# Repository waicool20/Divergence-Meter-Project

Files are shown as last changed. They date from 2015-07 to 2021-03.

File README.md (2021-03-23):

# Divergence Meter Project

This project is now archived, please head over to https://github.com/waicool20/Divergence-Meter-Project-v2 for latest iteration of the project

## Introduction
Hi~ I'm waicool20, this is the Divergence Meter Project! Just in case you're wondering what project this is about, it's actually a project to make the Divergence Meter from the anime Steins;Gate a reality (If you still don't know what that is, then I'm gonna start questioning why you're here lol, go google it). Basically it displays the current world line you're in. 

Well anyways originally this project is based on this guy's project: http://www.mindspring.com/~tomtitor/ and it has helped greatly so I guess give him some credit? I tried to improve his design by improving electronics design with power efficiency and mind-friendliness in mind (hence the AVR so we can code in C :D) I designed the thing in Diptrace, but I have also included Gerber/Drill files in a convenient zip so you can just hand it to some manufacturer to make some boards (remember to remind them that it's 2 separate boards in a single zip and not one!) included also are the schematic PDFs which are not quite convenient... orz anyways have a look around.

I just pulled this off my blog ( http://waicool20.com ) and it's not all the differences I think...feel free to help me expand this list :p

> Additional Features:
> - 5 switches possible! Could be less if you tweak the software
> - Buzzer/Speaker output 😀 hurray for alarms in the morning
> - Light Sensor to detect night time to conserve power and extend Nixie tube life (could probably act as a basic motion sensor with some software magic)
> - Improvements/Slight changes:
> - Should be able to fit 2x9V batteries instead of one so more portable cosplay time :D
> - Should be able to fit 2xAA RTC backup battery so it keeps track of time accurately for theoretically over a year.
> - Interrupt based instead of Polling to conserve even more battery
> - Uses the larger but cheaper and more available version of the HV5622
> - Integrated switching power supply instead of a bought module
> - Uses an AVR instead of a PIC (I chose it because it can be reprogrammed by AVR tools and a PICKIT2 if you happen to have any of those)
> - Mostly SMD parts to make look all good when your showing off the innards XD
> - Miku silhouette included
>
> Limitations:
> - Can only use the DS3232 RTC and not the DS1307

Features in a nutshell:
- 2 Alarms
- Adaptive Brightness (Brightness changes according to surroundings)
- Turn on/off display at certain times.
- 9V battery for portability and DC Jack for stationary setups
- 5 buttons for control
- Custom World Lines
- 32 Preset world lines from the anime/VN

## Project Structure
Well the Hardware and Software git branches are separate so that they can be developed independently easily.

Basically if you want the latest Software changes please switch to the software branch. Same thing for hardware. Though most often it will be the software branch that will be updated.

## About the licensing...
Well to keep it simple the hardware and the software are licensed with the TAPR OHL and GPLv3 respectively, if you are gonna use my work feel free to contact me at waicool20@gmail.com or not if that's how you swing. 

## Safety Disclaimer
**THIS PROJECT CONTAINS HIGH VOLTAGES (~170V) IT CAN KILL YOU IN THE WORST CASE SO BE CAREFUL.**  

The project has already minimized risk of contact with High Voltage (assuming you have a solder mask) so the only places you need to be careful are the parts around the LM3481, the HV pin on the board connector, and most of the pins on the Nixie Board. When constructing the device, please make sure no high voltage areas touch the case or anything that's not supposed to be "live", like seriously it will make your life easier.

When handling this device be aware that high voltage can still exist even when the device is completely powered off because of residual power in the capacitors, wait at least 3-5 seconds before touching anything on the pcb after unplugging the device.

Well you are at your own risk when you attempt this project, you can't hold me liable for anything that happens to you, your property or anybody/thing affected by your actions. 

El Psy Congroo,  
waicool20

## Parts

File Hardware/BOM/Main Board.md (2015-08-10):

| RefDes | Value | Name | Quantity |
|:---:|:---:|:---:|:---:|
| B1 | | CR2032 Bat. Holder | 1 |
| C1, C2, C3, C4, C6, C8, C10, C13 | 0.1uF | CAP_0805 | 8 |
| C5, C7, C9 |  100uF 16V | E. Cap 2 5D | 3 |
| C11 | 4.7uF 250V | E. Cap 3.5 8D | 1 |
| C12 | | F1772-410-2200-E3 | 1 |
| | | Any safety capacitor with 10 or 15mm pin pitch will do, capacitance should be 0.1uF | |
| D1 | | PMLL4148L | 1 |
| D2 | | MUR240 | 1 |
| J1 | | HDR-1x6 | 1 |
| J2 | | AVRISP | 1 |
| J3 | | DC Plug | 1 |
| J4 | | Power Select | 1 |
| J5 | | Battery | 1 |
| J6 | | ON/OFF | 1 |
| J7 | | SW1 | 1 |
| J8 | | SW2 | 1 |
| J9 | | SW3 | 1 |
| J10 | | SW4 | 1 |
| J11 | | SW5 | 1 |
| J12 | | SPEAKER | 1 |
| J13 | | LDR | 1 |
| | | The above pin headers (J1-J13) are optional, you can solder the wires directly to the PCB instead, refer to schematic for how many pins they are,
| J14 | | Board connector | 1 |
| L1 | 2.2uH | D52LC | 1 |
| L2 | 100uH | ELC16B101L | 1 |
|										  	 |			| As for the above 2 inductors I didn't actually use those parts, instead I had a factory custom make some for me. Iirc they were 1.5A and 4A rated respectively. |
| Q1 | | 2N4401 | 1 |
| Q2 | | IPB17N25S3-100  | 1 |
| | | Any mosfet with rating above 250V+ should do, but efficiency may drop if switch on/off is too slow |
| R1, R2, R3, R4, R5, R6, R7, R8, R9, R10, R11 | 1K | RES_0805 | 11 |
| R12 | 390K | RES_0805 | 1 |
| R13, R21, R22 | 100K | RES_0805 | 3 |
| R14 | 75K | RES_0805 | 1 |
| R15, R16, R17 | 200K | RES_0805 | 3 |
| R18 | 1.5K | RES_0805 | 1 |
| R19, R23, R24, R25, R26 | 4.7K | RES_0805 | 5 |
| R20 | 0.015 | RES_2512 | 1 |
| U1 | | ATtiny861A-SU | 1 |
| U2 | | DS3232SN# | 1 |
| U3 | | TPS62160DGKT | 1 |
| U4 | | LM3481MM/NOPB | 1 |

Resistor and capacitors specifications don't really matter, just keep the tolerance low and keep it in the same package (I just pulled those off the shelf, don't even know what brand they were XD )

Sorry if some of the above parts can be a little misleading as I mostly just pulled this off the BOM export function of diptrace. So please refer to the schematics or board files and check what that part actually is using the RefDes

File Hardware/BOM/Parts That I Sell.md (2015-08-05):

## Parts I sell, go shoot me an email at waicool20@gmail.com (All prices in USD):

| Part | Price | Usage |
|:----:|:-----:|:-----:|
| PCB  | $20 each, $40 for both boards | Well where else are you gonna solder all those parts together? |
| DC-DC converter inductors x2 | $3 | One of these are for the low voltage supply and the other for the high voltage supply |
| HV Safety Capacitors x 4 | $2 | 3 for ornament use and the other one for actual use on the high voltage supply circuit |
| Dummy super capacitor | $.75 | It's the left most capacitor you see on the divergence meter |
| IPB17N25S3-100 | $1 | Once again for the high voltage supply |
| DS3232SN | $7 | Real Time Clock IC for keeping time |
| Other parts | I pretty much have everything else in large amounts like misc resistors, capacitors, switches, battery holders etc. but I think it would cheaper if you just went to a local electronics store. The only things I don't have though are the ICs used in this project except for the the attiny861a. Have to think of a way to program SMD parts first though =__= |

You choose and pay for the shipping (From Hong Kong). Normal mail, speed mail, fedex, ups etc. I think we pretty much have every kind of delivery company here :/ but ehh some of them are crazy expensive.

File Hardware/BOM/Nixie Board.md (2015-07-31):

| RefDes | Value | Name | Quantity |
|---|---|---|---|
| C1, C2, C3 | 0.1uF | CAP_0805 | 3 |
| J1 | | PPTC071LFBN-RC | 1 |
| R1, R2, R3, R4, R5, R6, R7, R8 | 68K | RES400 | 8 |
| R9, R10, R11, R12, R13, R14, R15, R16, R17, R18, R19, R20, R21, R22, R23, R24 | 510K  | RES400 | 16 |
| U1, U2, U3 | | HV5622 | 3 |
| V1, V2, V3, V4, V5, V6, V7, V8 | | IN-14 - Inverted | 8 |

Sorry if some of the above parts can be a little misleading as I mostly just pulled this off the BOM export function of diptrace. So please refer to the schematics or board files and check what that part actually is using the RefDes

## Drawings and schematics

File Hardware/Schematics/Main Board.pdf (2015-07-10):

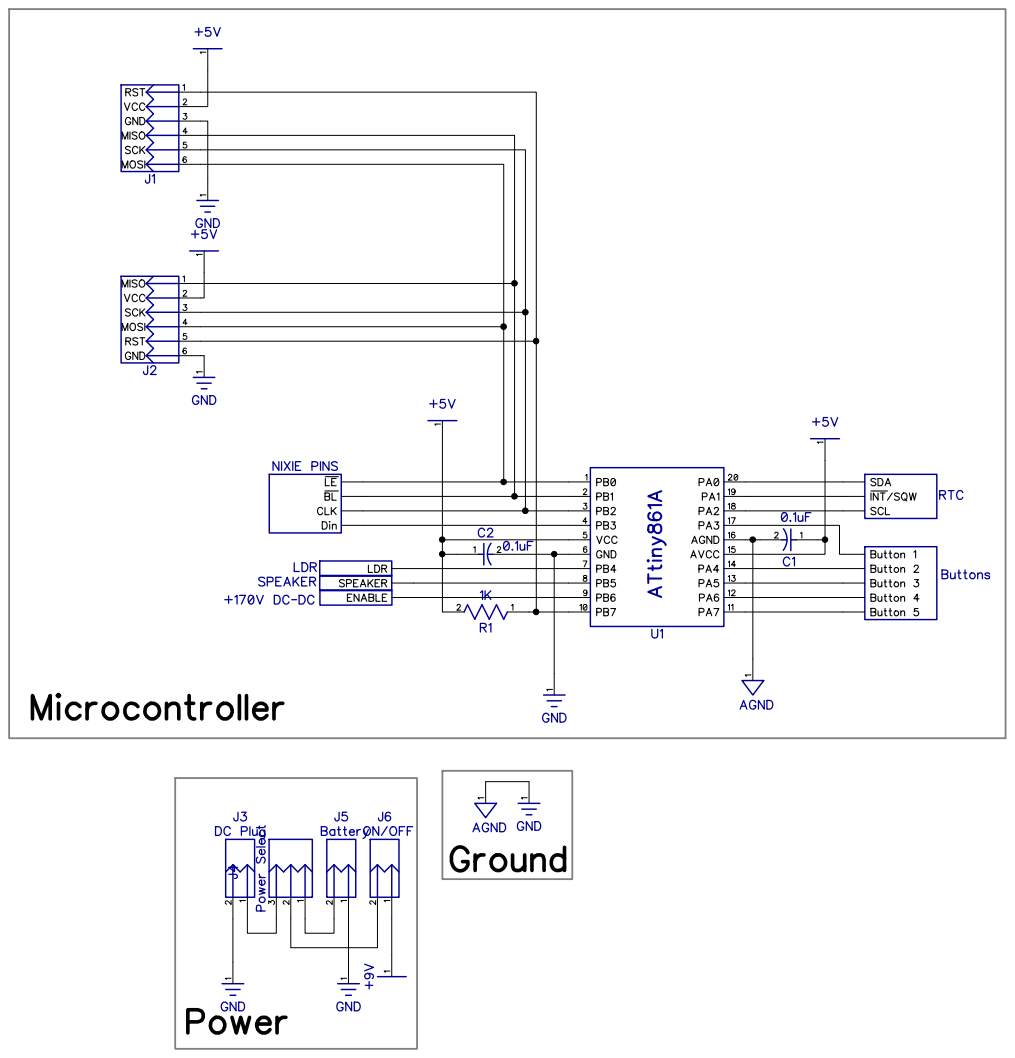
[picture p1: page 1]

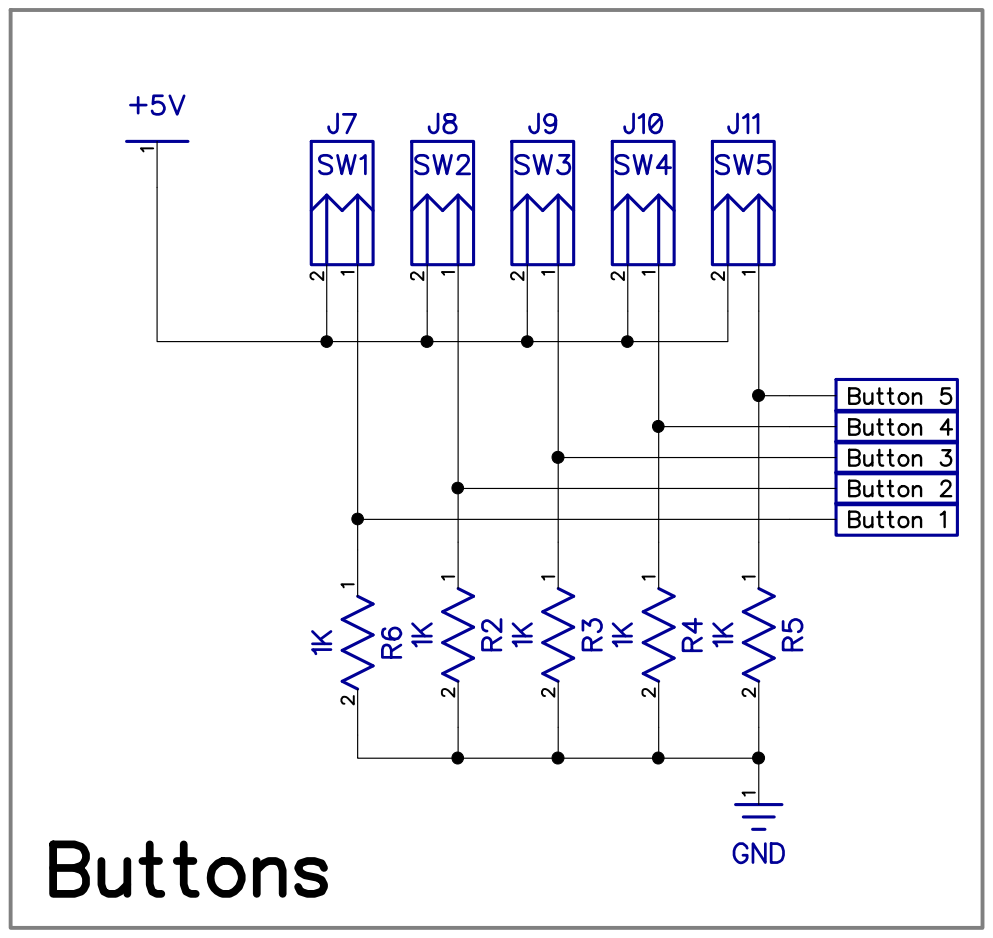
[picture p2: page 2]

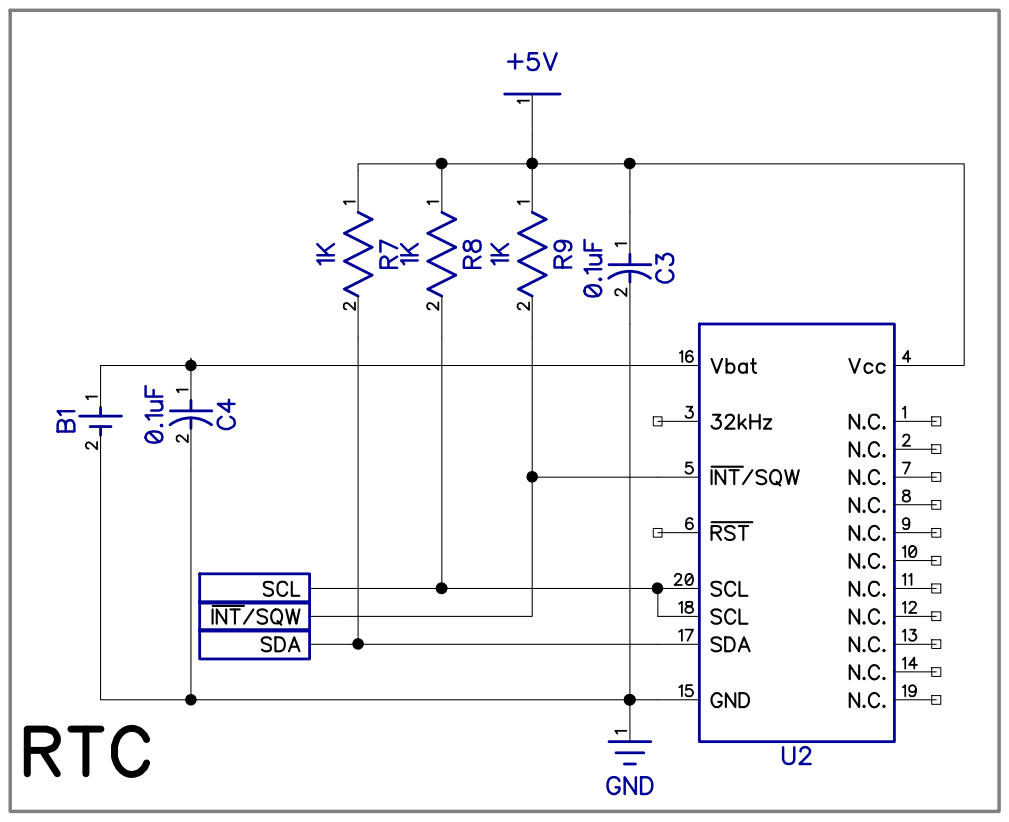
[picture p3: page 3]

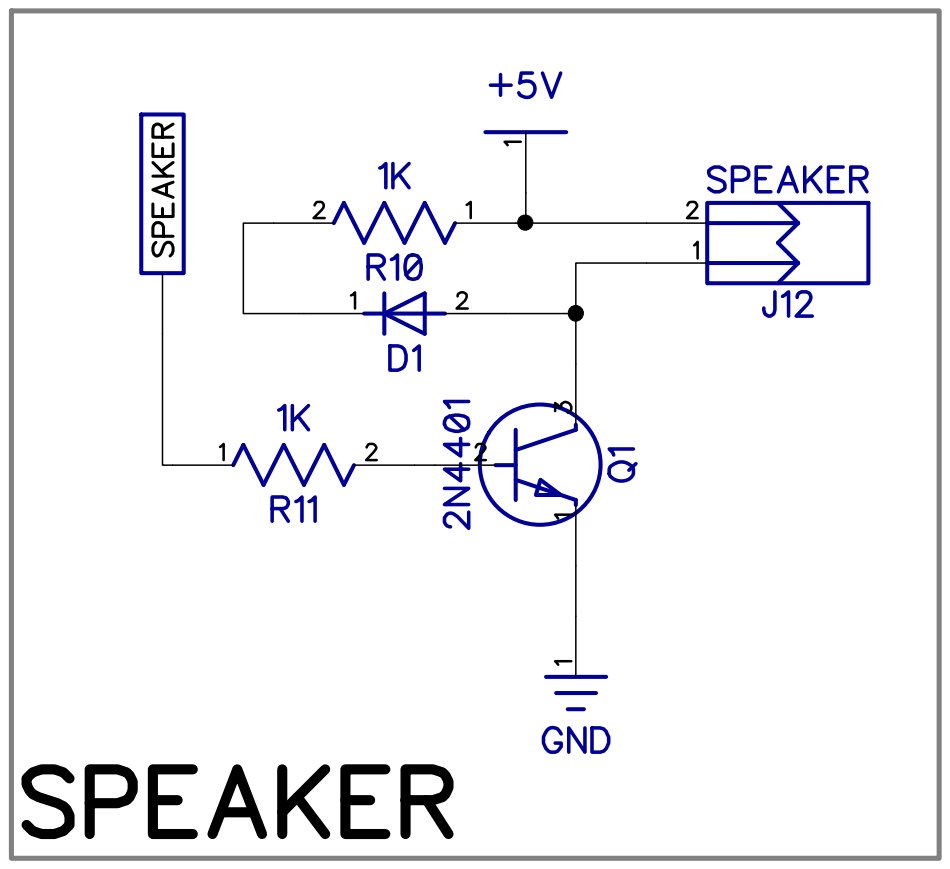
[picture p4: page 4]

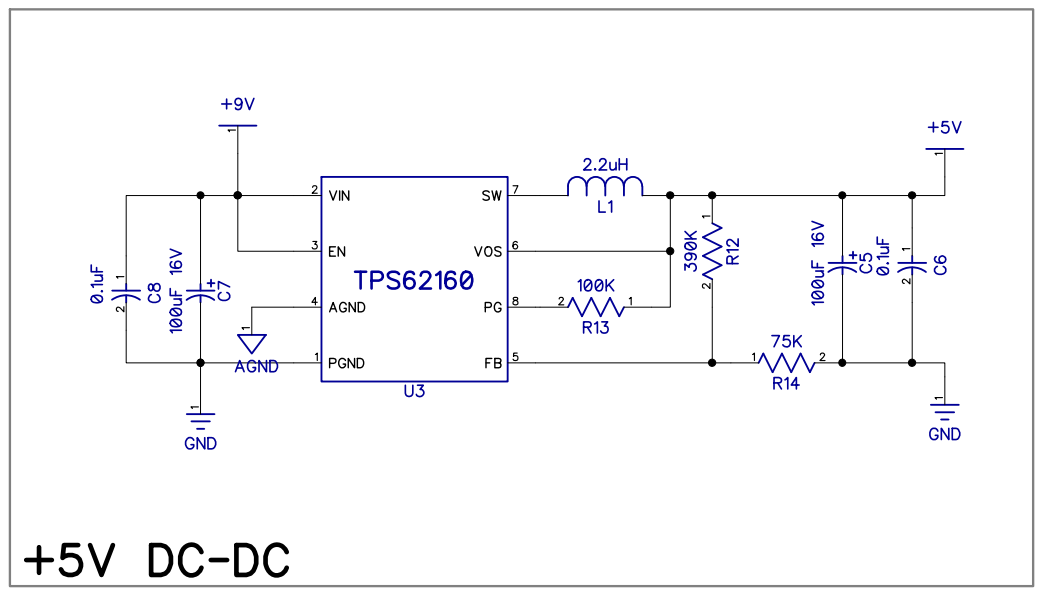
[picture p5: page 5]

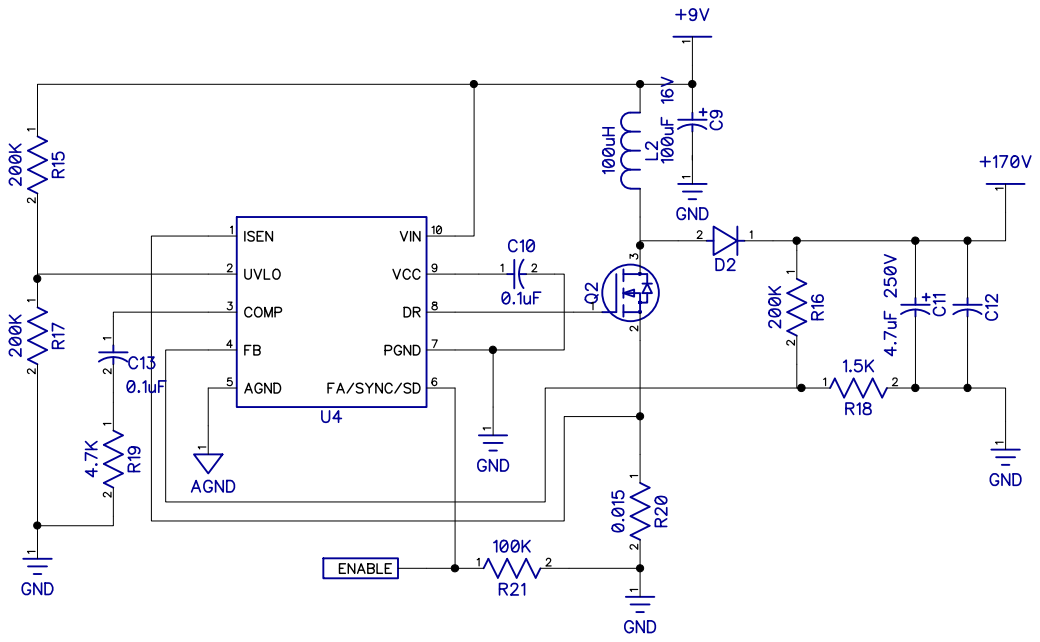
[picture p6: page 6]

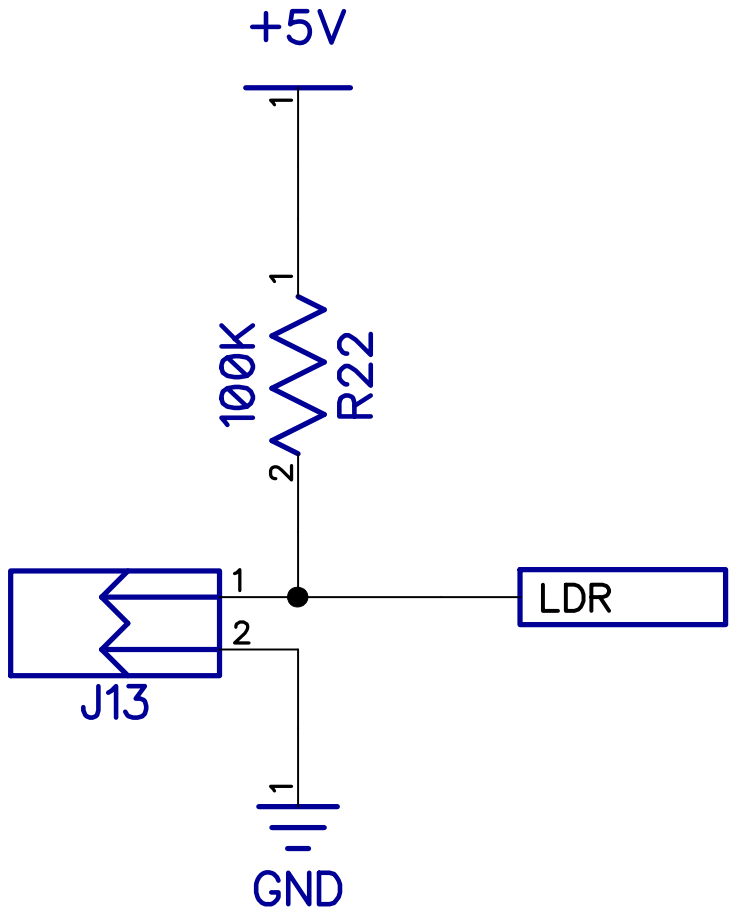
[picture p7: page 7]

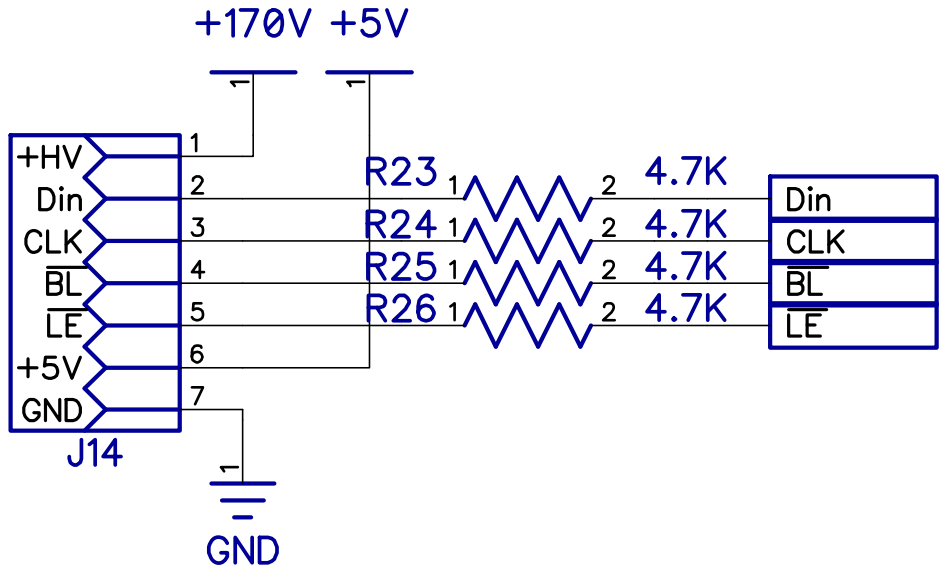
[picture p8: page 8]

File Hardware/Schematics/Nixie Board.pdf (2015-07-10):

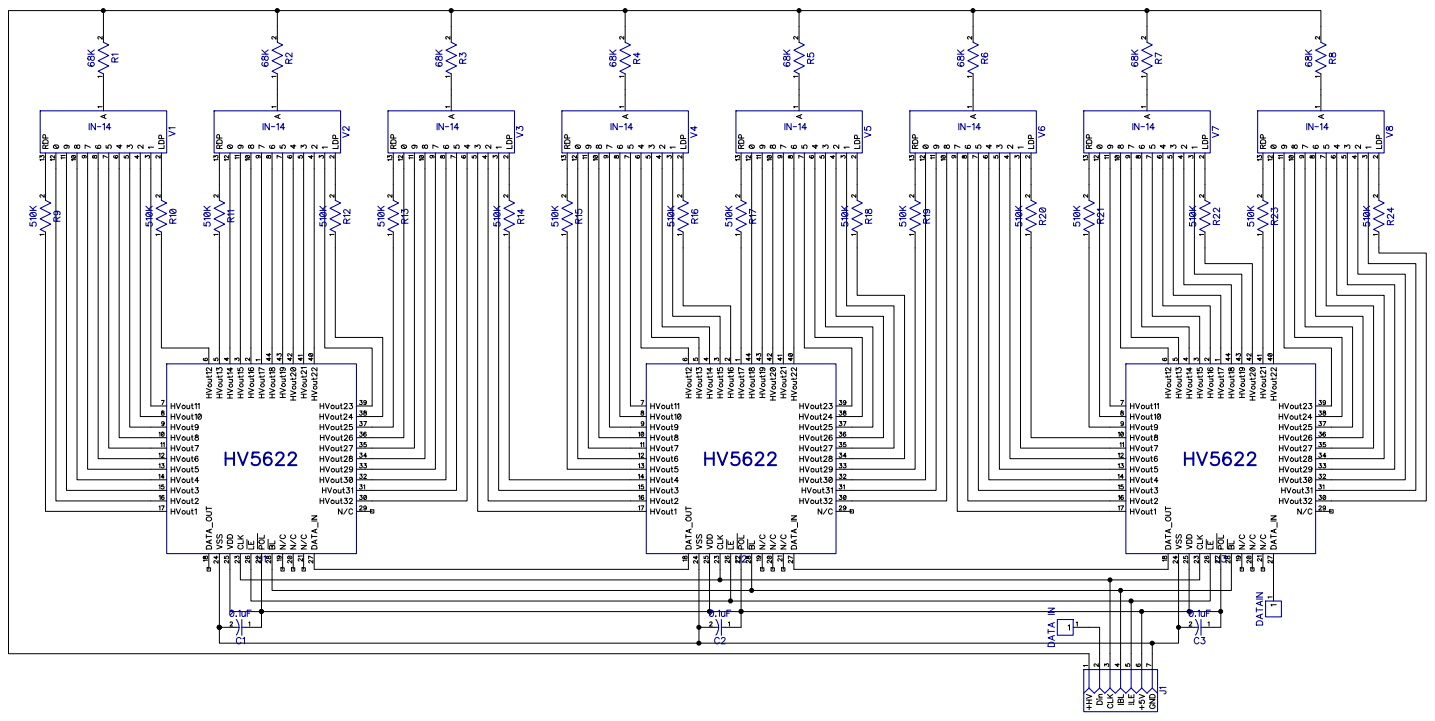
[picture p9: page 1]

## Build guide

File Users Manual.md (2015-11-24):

# Divergence Meter User's Manual

Learn how to use the divergence meter with this manual!

Buttons will be referred to as B1, B2, B3, B4, B5 going from left to right with the nixie tube digits facing towards you.

## All Modes

| Button | Short Press | Long Press | Pressed |
|:---:|:---:|:---:|:---:|
| B1 | Switch mode | Go to device settings | N\A |

## Clock Mode

This is the first mode that appears when the divergence meter boots up. The time format is displayed as HH-MM-SS. Every minute the 
tubes will be rolled to prevent cathode poisoning and the date and day of week will show up afterwards. 
The date format will depend on your settings, which can either be MM-DD-YY or DD-MM-YY. On the other hand, day of week 
is user defined so if your week starts on sunday then you can set that as 01 otherwise if your week starts on monday 
then you can set monday as 01 and sunday as 07

When you press B3 to arm an alarm, the two most middle tubes will indicate which alarm is active, the left tube will indicate alarm 1 and the right tube will indicate alarm 2.
1 means armed and 0 means disarmed.

Button Functions:

| Button | Short Press | Long Press | Pressed |
|:---:|:---:|:---:|:---:|
| B2 | Show date and day of week | Go to time **Settings mode** |  |
| B3 | Toggle alarms | Go to **Alarm Set mode** |  |
| B4 |  |  |  Roll a random world line |
| B5 |  |  | Toggle Brightness |

## Divergence Mode

This is the mode where you can play with world lines as much as you want, you can cycle through preset world lines from the anime/VN, roll a random world line or manually set your own world line by going to the **Divergence Edit Mode**.

Button Functions:

| Button | Short Press | Long Press | Pressed |
|:---:|:---:|:---:|:---:|
| B2 | Prev preset | Combo see below |  |
| B3 | Next preset | Combo see below |  |
| B4 |  |  |  Roll a random world line |
| B5 |  |  | Toggle Brightness |
| B2 + B3 |  | Go to **Divergence Edit Mode** |  |

## Divergence Edit Mode

This is the mode where you can enter any world line manually. It will then return to **Divergence Mode** after you set all the digits. Digits can be set from 0-9 and blank character. It will skip tube2 as it is always a decimal point.

Button Functions:

| Button | Short Press | Long Press | Pressed |
|:---:|:---:|:---:|:---:|
| B2 |  |  | Decrement |
| B3 |  |  | Increment |
| B4 | Next Tube |  |  |
| B5 | Prev Tube |  |  |

## Settings Mode

This is the mode where you can set different kind of parameters to change the meter's behaviour, refer to **All Modes** to see how to access this mode.  On the leftmost side there will be a number showing what setting you are currently configuring, and on the rightmost side it will show you its current value.
The resting and waking times are also set here. More on those below.

Settings:

| Number | Default | Min Value | Max Value | Description |
|:---:|:---:|:---:|:---:|:---:|
| 01 | 0 | 0 | 1 | 0 for 24H time, 1 for  12H time |
| 02 | 0 | 0 | 1 | 0 for MM-DD-YY dates, 1 for DD-MM-YY dates |
| 03 | 0 | 0 | 1 | 0 for silent buttons, 1 for beep on press |
| 04 | 0 | 0 | 23 | Combined with settings 05 to set the start time of resting time |
| 05 | 0 | 0 | 59 | Combined with settings 04 to set the start time of resting time |
| 06 | 0 | 0 | 23 | Combined with settings 07 to set the start time of waking time |
| 07 | 0 | 0 | 59 | Combined with settings 06 to set the start time of waking time |

Button Functions:

| Button | Short Press | Long Press | Pressed |
|:---:|:---:|:---:|:---:|
| B2 |  |  | Decrement |
| B3 |  |  | Increment |
| B4 | Next Setting |  |  |
| B5 | Prev Setting |  |  |

## Clock Set Mode

This is the mode where you can set your time, refer to **Clock Mode** to see how to access this mode. On the leftmost side there will be a number showing what setting you are currently configuring, and on the rightmost side it will show you its current value.

Settings:

| Number | Default | Min Value | Max Value | Description |
|:---:|:---:|:---:|:---:|:---:|
| 01 | 0 | 0 | 99 | Year |
| 02 | 0 | 1 | 12 | Month |
| 03 | 0 | 1 | 31 | Date |
| 04 | 0 | 1 | 7 | Day of week |
| 05 | 0 | 0 | 23 | Hours |
| 06 | 0 | 0 | 23 | Minutes |
| 07 | 0 | 0 | 59 | Seconds |

Button Functions:

| Button | Short Press | Long Press | Pressed |
|:---:|:---:|:---:|:---:|
| B2 |  |  | Decrement |
| B3 |  |  | Increment |
| B4 | Next Setting |  |  |
| B5 | Prev Setting |  |  |

## Alarm Set Mode

This is the mode where you can set the alarms, there are a total of 2 alarms, the main difference being that you can set the exact second in alarm 1 but not in alarm 2.

When you first enter this mode you will be given the choice to choose which alarm to set,
after which you can set the settings as below.

Settings:

| Number | Default | Min Value | Max Value | Description |
|:---:|:---:|:---:|:---:|:---:|
| 01 | 0 | 0 | 7 | Day of week, 0 means any day|
| 02 | 0 | 0 | 23 | Hours |
| 03 | 0 | 0 | 23 | Minutes |
| 04 | 0 | 0 | 59 | Seconds |

Button Functions:

| Button | Short Press | Long Press | Pressed |
|:---:|:---:|:---:|:---:|
| B2 |  |  | Decrement |
| B3 |  |  | Increment |
| B4 | Next Setting |  |  |
| B5 | Prev Setting |  |  |

## Rest Mode

This is the mode where the device will turn off the display to conserve energy and extend battery life. The time to turn off and turn on the display can be set in **Settings Mode**. This mode cannot be accessed manually. When waking up, it will always go back to **Clock Mode**.

| Button | Short Press | Long Press | Pressed |
|:---:|:---:|:---:|:---:|
| All |  |  | Wake up |

## Other

### Brightness levels:

The brightness of the device can be toggled through 11 different light intensities, please refer to the above to see how. Manual brightness levels range from 0-9 while brightness level 10 turns on the adaptive brightness functionality, the device will then adapt to the current light level of the environment and will set the brightness accordingly, basically it turns darker in dark environments to save power and it will turn brighter in brighter environments so that the display can be seen properly. Please note that the device detects brightness through the LDR (Light Dependent Resistor), if its covered by something or just that section is in a shaded region then the device will respond as if it were in that environment.

### Power Supply
The device provides 2 power supply pcb pads, one for the batteries and one for the DC jack. Please choose a DC jack according to your size preference when making your own device. Though please choose a power supply that can at least provide 12V, otherwise the nixie tubes will appear as if they had cathode poisoning. The maximum power supply voltage at any time should not exceed 18V. The battery terminals can be left floating in the case without any worries that it will short out, as the terminals are disconnected by the power select switch.

## FAQ

//Ask me some questions first

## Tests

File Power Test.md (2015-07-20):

#Power Test

People usually say the difference between fooling around and science is writing results down.
So to keep up some of the "scientific spirit", here I present some data that might be useful :)

All test were conducted in Clock Mode. Taking 550mAh as the standard capacity of the 9V Alkaline battery.

| Power Supply | Total Voltage | Current | Watts (VI) | Brightness | Estimated Supply Life |  
|:---:|:---:|:---:|:---:|:---:|:---:|
| 2x9V Alkaline Battery(Standard Energizers) | 14.6V | 47.6mA | 0.695 | 0(lowest) | 550/47.6 = 11.6 Hours |  
| 2x9V Alkaline Battery(Standard Energizers) | 14.6V | 126.2mA | 1.84 | 9(lowest) | 550/126.2 = 4.36 Hours |

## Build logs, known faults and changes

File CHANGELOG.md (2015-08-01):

# DIVERGENCE METER PROJECT CHANGELOG 

For changes to the software of the project please jump to the # Software section.  
For changes to the hardware of the project please jump to the # Hardware section.  

## Software

### [UNRELEASED] - [UNRELEASED]

### [0.2.3a] - 2015-08-01
#### Fixing
- Getting 9 when rolling for a BLANK digit (Intermittent)

### [0.2.2a] - 2015-08-01
#### Changing
- Smooth roll transitions into date at the end of minute

#### Fixing
- World line rolling in clock mode

### [0.2.0a] - 2015-07-26
#### Adding
- BOM
- User Manual

#### Changing
- Visually correct world line rolling

#### Fixing
- Display errors on tube3 and tube6

### [0.1.0a] - 2015-07-23
#### Adding
- Alarms
- Resting hours
- Beep on button press

#### Changing
- Decimal points are now independent of digits

#### Fixing
- Divergence Editing does not roll properly
- Divergence Editing does not return to tube1 properly
- Date not showing correctly

### [0.0.1a] - 2015-07-19
#### Added
- Alpha testing release

## Hardware

### [UNRELEASED] - [UNRELEASED]
#### Adding
- Buck boost converter
- Possibly a screw hole for a 2xAA holder

#### Changing
- Correcting Shift Register layout for easier data input
- Using internal pullup resistors in the MCU instead

### [1.2] - 2015-07-19
#### Added
- Initial Release. Fully functional

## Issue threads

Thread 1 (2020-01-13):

Problem

zhuiwang, 2020-01-13:
Hello, I made a Divergence Meter according to your project, but it seems that in the working part of Attiny861a, the flash programming is successful, although the fuses programming fails, but the extended reading value is 0xff, which is a meaning with your definition of 0x01; It should be that the programming is successful, the display data of the tube is confusing, and only the dimming can be controlled. I would like to ask, does this project require PCB materials? I ’m using FR-4. Is it a quality problem of the DIN CLK signal transmission? Thank you

waicool20, 2020-01-13:
0xff is the default unprogrammed state for the extended fuses. If you have a logic analyzer use that to verify that bits are being shifted into the shift registers on the DIN and CLK line. Did you etch your own PCBs? I'm also using FR-4 PCBs

zhuiwang, 2020-01-13:
When I leave it for a period of about 30min, after powering on, the normal display time starts to jump normally (hours, minutes, seconds), but a few seconds, it will enter a chaotic digital display (not the world line change). The software is the same. If there is no problem, should this situation be a hardware problem?

waicool20, 2020-01-13:
It might be hardware, check for loose connections and that the voltage supply is stable and high enough typically 12v+

zhuiwang, 2020-01-13:
I made two main boards, both of which can light up the tubes, but the data is messy. It's a pity that I don't have the relevant test equipment, and I have carefully checked the welding, but there are not many ideas for solving this hardware problem. Do you have an extra main board (only main board)? Can you send me one if any? (I pay you the main board production price and courier costs. I'm in mainland China. Express delivery should be very convenient.)

waicool20, 2020-01-13:
Did you etch your own boards or did you get professional PCBs? Not convenient for me to solder anything, but PCB is ok. Mail me your wechat ID and we can discuss further arrangements.

zhuiwang, 2020-01-14:
> 您是蚀刻自己的电路板还是获得专业的PCB？我不方便焊接任何东西，但PCB可以。给我发送您的微信ID，我们可以讨论进一步的安排。

wechatid: Mashiros       Thanks

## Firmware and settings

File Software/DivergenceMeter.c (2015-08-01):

/*  GPLv3 License
 *
 *   Copyright (c) Divergence Meter Project by waicool20
 *
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
 *  You should have received a copy of the GNU General Public License
 *  along with this program.  If not, see <http://www.gnu.org/licenses/>.
 */

/*
 * Main Program Entry of the Divergence Meter Project.
 * General logic will be implemented here.
 */

#include "DivergenceMeter.h"

#include <stdint.h>
#include <stdbool.h>

#include <avr/io.h>
#include <avr/fuse.h>
#include <avr/interrupt.h>
#include <avr/sleep.h>
#include <avr/power.h>

#include "constants.h"
#include "modes/clockMode.h"
#include "modes/clockSetMode.h"
#include "modes/alarmSetMode.h"
#include "modes/divergenceEditMode.h"
#include "modes/divergenceMode.h"
#include "modes/settingsMode.h"
#include "modes/restMode.h"
#include "settings.h"
#include "util/display.h"
#include "util/RNG.h"

FUSES = { .low = 0xE2, .high = 0xDF, .extended = 0x01, };

/* Prototypes */

static void DivergenceMeter_init();

/* Volatile Variables (Modifiable by ISR)*/

static volatile uint8_t clockCount;
static volatile uint16_t delayCount;
static volatile uint8_t currentMode;
static volatile uint8_t oldSecond;

static volatile uint8_t buzzDuration;
static volatile uint8_t buzzedDuration;
static volatile uint8_t buzzInterval;
static volatile uint8_t buzzIntervalCount;
static volatile uint8_t buzzTimes;

volatile bool justEnteredMode[7];

volatile uint16_t buttonCount[5];
volatile bool buttonIsPressed[5];
volatile bool buttonShortPressed[5];
volatile bool buttonLongPressed[5];

volatile uint16_t ringDuration;
volatile uint16_t beepIncCount;
volatile uint8_t beeps;

/* Normal Variables */

bool shouldRoll = false;

/* Main Code Start */
int main() {
  DivergenceMeter_init();
  while (1) {
    if (oldSecond != settings.time[SECONDS]) {
      oldSecond = settings.time[SECONDS];
      if (ringDuration > 0) {
        ringDuration--;
      }
      beepIncCount++;
      if (ringDuration) {
        if (!(settings.time[SECONDS] & 0x01)) {
          DivergenceMeter_buzz(2, 8, beeps);
        }
      }
    }
    if (beepIncCount > BEEP_INC_INTERVAL_S) {
      beepIncCount = 0;
      if (beeps < MAX_BEEPS) {
        beeps++;
      }
    }
    if (settings.main[BRIGHTNESS] == 10) {
      display_updateAdaptiveBrightness();
    }
    switch (currentMode) {
      case CLOCK_MODE:
        clockMode_run();
        break;
      case ALARM_SET_MODE:
        alarmSetMode_run();
        break;
      case DIVERGENCE_MODE:
        divergenceMode_run();
        break;
      case DIVERGENCE_EDIT_MODE:
        divergenceEditMode_run();
        break;
      case SETTINGS_MODE:
        settingsMode_run();
        break;
      case CLOCK_SET_MODE:
        clockSetMode_run();
        break;
      case REST_MODE:
        restMode_run();
        break;
    }
    DivergenceMeter_sleep();
  }
  return 0;
}

static void tmr0_init() {
  TCCR0A = (1 << TCW0);  //16 bit width
  TCCR0B = (1 << CS01);  //x8 prescaler
  uint16_t val = 10000;  // 10ms interval calculated by (Seconds)/(1/(((System Clock))/prescaler))
  OCR0B = (val >> 8);
  OCR0A = (uint8_t) val;
  TIMSK = (1 << OCIE0A);  //Compare Match interrupt enable
}

static void ADC_init() {
  ADMUX = (1 << ADLAR) | 0x07;  //ADC channel 7
  ADCSRA = (1 << ADEN) | (1 << ADPS2) | (1 << ADPS1) | (1 << ADATE);
  ADCSRB = (1 << ADTS1) | (1 << ADTS0);
  ADCSRA |= (1 << ADSC);
  while (ADCSRA & (1 << ADSC))
    ;
}

static void DivergenceMeter_init() {
  //Initialize IO
  DDRA &= ~((1 << ALARM_INT) | (1 << BUTTON1_PIN) | (1 << BUTTON2_PIN)
      | (1 << BUTTON3_PIN) | (1 << BUTTON4_PIN) | (1 << BUTTON5_PIN));
  DDRB = (1 << LE) | (1 << BL) | (1 << CLK) | (1 << DIN) | (1 << SPEAKER);
  MCUCR = (1 << PUD);
  //Global interrupt enable
  sei();

  settings_init();
  settings_clearAlarmFlagsDS3232();
  ADC_init();
  RNG_seed();
  tmr0_init();
  display_init();
}

/* Timer0 Interrupt Code, ran every 10ms as configured*/

ISR(TIMER0_COMPA_vect) {
  for (int8_t i = 4; i >= 0; i--) {
    if (bit_is_set(PINA, i+3) && buttonCount[i] < 65535) {
      buttonCount[i]++;
    } else {
      buttonCount[i] = 0;
      buttonIsPressed[i] = false;
      buttonShortPressed[i] = false;
      buttonLongPressed[i] = false;
    }

    if (buttonCount[i] > (BUTTON_LONG_PRESS_MIN_DURATION_MS / 10)) {
      buttonIsPressed[i] = true;
      buttonShortPressed[i] = false;
      buttonLongPressed[i] = true;
    } else if (buttonCount[i] > (BUTTON_SHORT_PRESS_MAX_DURATION_MS / 10)) {
      buttonIsPressed[i] = true;
      buttonShortPressed[i] = false;
      buttonLongPressed[i] = false;
    } else if (buttonCount[i] >= (BUTTON_SHORT_PRESS_MIN_DURATION_MS / 10)) {
      if (settings.main[BEEP_ON_PRESS]) {
        DivergenceMeter_buzz(2, 2, 1);
      }
      buttonIsPressed[i] = true;
      buttonShortPressed[i] = true;
      buttonLongPressed[i] = false;
    }
  }
  if (buttonShortPressed[BUTTON1]) {
    RNG_seed();
    switch (currentMode) {
      case SETTINGS_MODE:
        settings_writeSettingsDS3232();
        break;
      case REST_MODE:
        display_on();
        break;
    }
    currentMode = currentMode < DIVERGENCE_MODE ? currentMode + 1 : CLOCK_MODE;
    justEnteredMode[currentMode] = true;
  } else if (buttonLongPressed[BUTTON1] && currentMode != SETTINGS_MODE) {
    DivergenceMeter_switchMode(SETTINGS_MODE, false);
  }
  if (++clockCount > 9 && currentMode != CLOCK_SET_MODE) {
    settings_readTimeDS3232();
    clockCount = 0;
  }
  if (delayCount > 0) {
    delayCount--;
  }
  if (buzzTimes) {
    if (buzzIntervalCount++ == buzzInterval) {
      buzzIntervalCount = 0;
      PORTB |= (1 << SPEAKER);
      if (buzzedDuration++ == buzzDuration) {
        buzzedDuration = 0;
        PORTB &= ~(1 << SPEAKER);
        buzzTimes--;
      }
    }
  }
  if (bit_is_clear(PINA, ALARM_INT)) {
    ringDuration = (ALARM_RING_M * 60);
    beeps = 1;
    beepIncCount = 0;
    DivergenceMeter_switchMode(CLOCK_MODE, false);
    display_on();
    settings_clearAlarmFlagsDS3232();
  }
  TCNT0H = 0x00;
  TCNT0L = 0x00;
}

/* Misc Code */

static bool DivergenceMeter_shouldNotRoll() {
  return currentMode != DIVERGENCE_MODE && !shouldRoll;
}

void DivergenceMeter_rollWorldLine(bool rollTube2, uint8_t result[8]) {
  uint8_t randChar[8] = {
      ((RNG_nextChar() + ROLL_CONST) * 10) + (10 - display.tube[TUBE1]) + result[TUBE1],
      ((RNG_nextChar() + ROLL_CONST) * 10) + (10 - display.tube[TUBE2]) + result[TUBE2],
      ((RNG_nextChar() + ROLL_CONST) * 10) + (10 - display.tube[TUBE3]) + result[TUBE3],
      ((RNG_nextChar() + ROLL_CONST) * 10) + (10 - display.tube[TUBE4]) + result[TUBE4],
      ((RNG_nextChar() + ROLL_CONST) * 10) + (10 - display.tube[TUBE5]) + result[TUBE5],
      ((RNG_nextChar() + ROLL_CONST) * 10) + (10 - display.tube[TUBE6]) + result[TUBE6],
      ((RNG_nextChar() + ROLL_CONST) * 10) + (10 - display.tube[TUBE7]) + result[TUBE7],
      ((RNG_nextChar() + ROLL_CONST) * 10) + (10 - display.tube[TUBE8]) + result[TUBE8],
  };

  uint8_t maxNumber = 0;
  for (int8_t i = TUBE8; i >= TUBE1; i--) {
    if (maxNumber < randChar[i]) {
      maxNumber = randChar[i];
    }
  }

  for (uint8_t i = 0; i < maxNumber; i++) {
    if (DivergenceMeter_shouldNotRoll()) {
      return;
    }
    for (int8_t j = TUBE8; j >= TUBE1; j--) {
      if (!rollTube2 && j == TUBE2) {
        display_setTube(j, BLANK, true, false);
        continue;
      }
      if (randChar[j]) {
        if (display.tube[j] < 9) {
          display_setTube(j, display.tube[j] + 1, false, false);
        } else {
          display_setTube(j, 0, false, false);
        }
        randChar[j]--;
      }
      if (result[j] == BLANK && randChar[j] < 5) {
        display_setTube(j, BLANK, false, false);
      }
    }
    display_update();
    for (uint8_t j = (ROLL_INTERVAL_MS / 10); j > 0; j--) {
      if (DivergenceMeter_shouldNotRoll()) {
        return;
      }
      DivergenceMeter_delayCS(s2cs(0.01));
    }
  }
}

void DivergenceMeter_rollRandomWorldLine(bool rollTube2) {
  uint8_t results[8] = { (
      RNG_nextByte() > 235 ? BLANK : (RNG_nextByte() > 195 ? 1 : 0)),
      RNG_nextChar(), RNG_nextChar(), RNG_nextChar(), RNG_nextChar(),
      RNG_nextChar(), RNG_nextChar(), RNG_nextChar() };
  DivergenceMeter_rollWorldLine(rollTube2, results);
}

void DivergenceMeter_rollRandomWorldLineWithDelay(bool rollTube2) {
  DivergenceMeter_rollRandomWorldLine(rollTube2);
  for (uint16_t i = (ROLL_DISPLAY_SECONDS * 100); i > 0; i--) {
    if (DivergenceMeter_shouldNotRoll()) {
      return;
    }
    DivergenceMeter_delayCS(s2cs(0.01));
  }
}

void DivergenceMeter_showBrightness() {
  display_showCurrentBrightness();
  DivergenceMeter_delayCS(s2cs(BRIGHTNESS_DISPLAY_S));
}

void DivergenceMeter_delayCS(uint16_t delay_cs) {
  delayCount = delay_cs;
  while (delayCount) {
    DivergenceMeter_sleep();
  }
}

void DivergenceMeter_sleep() {
  set_sleep_mode(SLEEP_MODE_IDLE);
  sleep_enable()
  ;
  sleep_bod_disable();
  sei();
  power_adc_disable();
  power_usi_disable();
  sleep_disable()
  ;
  power_adc_enable();
}

void DivergenceMeter_switchMode(uint8_t mode, bool silent) {
  currentMode = mode;
  justEnteredMode[mode] = !silent;
}

void DivergenceMeter_buzz(uint8_t duration_cs, uint8_t interval, uint8_t times) {
  buzzDuration = duration_cs;
  buzzInterval = interval;
  buzzTimes = times;
}

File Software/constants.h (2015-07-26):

/*  GPLv3 License
 *
 *   Copyright (c) Divergence Meter Project by waicool20
 *
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
 *  You should have received a copy of the GNU General Public License
 *  along with this program.  If not, see <http://www.gnu.org/licenses/>.
 */
#ifndef CONSTANTS_H_
#define CONSTANTS_H_

#define s2cs(a) (a*100)

#define TUBE1 0
#define TUBE2 1
#define TUBE3 2
#define TUBE4 3
#define TUBE5 4
#define TUBE6 5
#define TUBE7 6
#define TUBE8 7

#define ROLL_CONST 3 //Constant for when rolling a world line a larger value makes it roll longer
#define ROLL_INTERVAL_MS 25
#define ROLL_DISPLAY_SECONDS 1

#define ALARM_INT PA1

/* LP: Long Press                                                                                                         */
/*                   |  ALL   |       CLOCK                         | DIVERGENCE                        |   SETTINGS    | */
#define BUTTON1 4 // |  MODE  |                                     |                                   |               |
#define BUTTON2 3 // |        | -/DATE              LP:Edit Time    | -/Prev        --|--EDIT MODE      | -             |
#define BUTTON3 2 // |        | +/ARM/DISARM ALARM/ LP:Edit Alarm   | +/Next        --|                 | +             |
#define BUTTON4 1 // |        | ROLL/CONFIRM                        | ROLL/CONFIRM                      | CONFIRM       |
#define BUTTON5 0 // |        | BRIGHTNESS/BACK                     | BRIGHTNESS/BACK                   | Back          |
#define BUTTON1_PIN PA3
#define BUTTON2_PIN PA4
#define BUTTON3_PIN PA5
#define BUTTON4_PIN PA6
#define BUTTON5_PIN PA7

#define BUTTON_SHORT_PRESS_MIN_DURATION_MS 40
#define BUTTON_SHORT_PRESS_MAX_DURATION_MS 60
#define BUTTON_LONG_PRESS_MIN_DURATION_MS 1200

#define DATE_DISPLAY_S 1
#define DAY_DISPLAY_S 1
#define ALARM_ARM_DISPLAY_S 0.4
#define BRIGHTNESS_DISPLAY_S 0.25

#define LE PB0
#define BL PB1
#define CLK PB2
#define DIN PB3
#define SPEAKER PB5
#define HV_DISABLE PB6

#define BLANK 10
#define DS3232 0xD0

#define ALARM1 1
#define ALARM2 2
#define ALARM_RING_M 10
#define MAX_BEEPS 10
#define BEEP_INC_INTERVAL_S 20

#define CLOCK_MODE 0
#define DIVERGENCE_MODE 1

#define SETTINGS_MODE 2
#define DIVERGENCE_EDIT_MODE 3
#define ALARM_SET_MODE 4
#define CLOCK_SET_MODE 5
#define REST_MODE 6

#endif /* CONSTANTS_H_ */

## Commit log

2015-07-10 Initial Commit
    Hardware: REV1.2
    Software: Test Software
    [Board.gbr, BoardOutline.gbr, Bottom.gbr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]
2015-07-11 Added display code and cleaned up code
    The display code makes it easier to change the nixie tube values. Some optimization can be done.
2015-07-11 Added I2C library and slightly optimized display file
    * Replaced cases with defaults in the display code
    * Added Fleury's I2C Library
    * Changed makefile so it can link assembly and c files
    * Added readme
    [Divergence_Meter.c]
2015-07-12 Added brightness control for the display
    *Brightness control via timer1 clocking the blanking pin
    *Removed unused libraries
    *Reduced delay
2015-07-13 Refactored code and added basic clock mode
    * Refactored all code
    * Added code to read from ADC (LDR)
    * Added Random Number Generator using time and light values as seeds.
    * Changed display code to use structs
    * Added display_on() and display_off() to turn HV supply on and off
    * Added basic clock display code
    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
2015-07-14 Added mode changing and finished divergence mode
    * Finished Divergence Mode
    * Improved Button debouncing
    * Added World Line constants
    * Refactored Code
    * Changed all variable types to standard integer types
2015-07-14 Resetting currentTube on DivergenceEditMode entry
    If mode was switched while editing, currentTube is not reset, this causes undesirable behaviour when re entering
    DivergenceEditMode
    [DivergenceMeter.c]
2015-07-14 Organized code
    * Organized code into suitable categories
    * Made it roll when switching world line presets
    * Added rollWithDP just in case
    * Made it roll every minute (00 second) then show date
    * Rolling now accepts bool to roll tube2 or not
    * Moved DS3232 time syncronization to timer0 isr
2015-07-15 Changed default brightness to 5
    Looks same compared to level 9, might as well save power/extend the life of the tubes
2015-07-15 Switched Button 3 and 4 to give a more logical function arrangement
    It just makes more sense...
    * Button 3 and Button 4 functions were swapped
    * Added more button suggestions
    [DivergenceMeter.c, constants.h]
2015-07-16 Fixing some button press detection code
    * Now detecting button press length properly
    * Combined short || long press boolean to single button_is_pressed flag
    * Reordered some button checks
    * Better IO assignment code
    [DivergenceMeter.c, constants.h]
2015-07-16 Changed settings mode activation method -> long press button1
    * removed time since last pressed variables
2015-07-16 Added adaptive brightness
    Display changes brightness according to the current lighting conditions(using the LDR as the sensor)
    * Put back the sleep code in the while loop, lol fail
    * Added Timer0 matchA triggers
    * Pressing Button5 while adaptive brightness is on will switch to manual brightness
    * Long press Button5 will turn adaptive brightness back on (shows 99)
    * Added defines for format bits
    [DivergenceMeter.c, display.c, settings.c]
2015-07-16 Saving program space my making a generic tube handling function
2015-07-16 Refactored settings to use arrays
    * Added some future settings to implement
    * Added some future modes to implement
    * Added more DS3232 interface functions
    * Fixed display blinking in some cases because of bad i2c termination (did not send nak)
    [DivergenceMeter.c, constants.h, display.c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]
2015-07-17 Finished settings mode
    * Settings mode now finished
    * Removed adaptive brightness settings and instead added it as level 10 when toggling
    * Decided to store all settings in DS3232 SRAM instead of eeprom
    * Default settings are copied on first boot (out of factory/after replacing battery)
    * Added convenience functions to write settings to DS3232
2015-07-18 Finished clock setting mode, improved delay
    * Now able to set time by long press button 2 in clock mode
    * No longer using avr delay library, instead delay using timer0, max resolution is in 0.01 seconds
    * helper s2cs() macro provided to convert seconds to centiseconds
    * Now showing day of week(number) after showing date
    * Added BCD util file, might need to add subtraction and addition later on
    [DivergenceMeter.c, constants.h, display.c]
2015-07-19 Fixed Divergence Edit mode
    * Stopped rolling after setting a world line
    * Jumping back to tube1 now works correctly while editing
    [DivergenceMeter.c]
2015-07-19 Added functions to shiftregister code
    Skips the while loop if only sending 1 zero or one to the shiftregisters
    [display.c, shiftregister.c]
2015-07-19 Modified display code
    * Decimal points are now independent of the tube digit
    * Can now turn on both decimal points at the same time,
    however point is too faint to be seen when turned on with a digit
    * Removed unused data in world lines
2015-07-20 Did some power consumption tests
2015-07-21 Fixed wrong fuses and added alarm test code
    * PB5 wasnt working due to wrong fuses making it impossible to control the logic.
    * Added some alarm test code, Button 3 in clock mode makes a beep
    [DivergenceMeter.c]
2015-07-21 Fixed Meter not waking up from Rest Mode properly
    [DivergenceMeter.c]
2015-07-23 Implemented alarms, no arming/disarming yet
    * Now able to set Alarm1 and Alarm 2
    * Added Buzzer Code
    * Added Optional beep when pressing the buttons (defaulted off)
    * Not gonna roll while alarm is active
    * Moved non-time critical stuff to main away from timer isr
    [DivergenceMeter.c, constants.h, settings.c]
2015-07-25 Fixed some display errors and slightly changed the RNG
    [DivergenceMeter.c, display.c]
2015-07-25 Made world line rolling more visually correct
    * Now stops rolling random tubes while rolling for a world line
    * Cannot set a fixed time anymore :/
    * Fixed RNG stuff
    * Could use some optimization
    [DivergenceMeter.c, constants.h]
2015-07-26 Added BOM
    [Main Board.csv, Nixie Board.csv]
2015-07-31 Update and rename Main Board.csv to Main Board.md
    [Main Board.csv]
2015-07-31 Update and rename Nixie Board.csv to Nixie Board.md
    [Nixie Board.csv]
2015-08-01 Fixed minor mistake
    * Button 4 in clock mode doesnt roll tube 2 anymore
    * Minute rolling rolls tube2
2015-08-01 Fixing world line roll bug
    The display would roll to 9 for some reason when rolling to BLANK, unsure if this really fixed it as it only happens occasionally, further testing needed
    [DivergenceMeter.c]
2015-08-10 Update Main Board.md
    BR2032 Was a bit misleading

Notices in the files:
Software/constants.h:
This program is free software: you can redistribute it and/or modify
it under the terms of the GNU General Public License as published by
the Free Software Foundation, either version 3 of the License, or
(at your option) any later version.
